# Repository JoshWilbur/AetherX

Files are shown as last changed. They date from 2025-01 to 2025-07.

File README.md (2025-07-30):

# AetherX

AetherX is a precision environmental sensor which can gather a number of statistics in real time. This device was designed with ease of use and portability in mind. This project is in a functional state and is considered "complete" for the time being. All features of this project, minus the microphone, are functional and calibrated. In the future, I plan to revisit this project to make improvements.

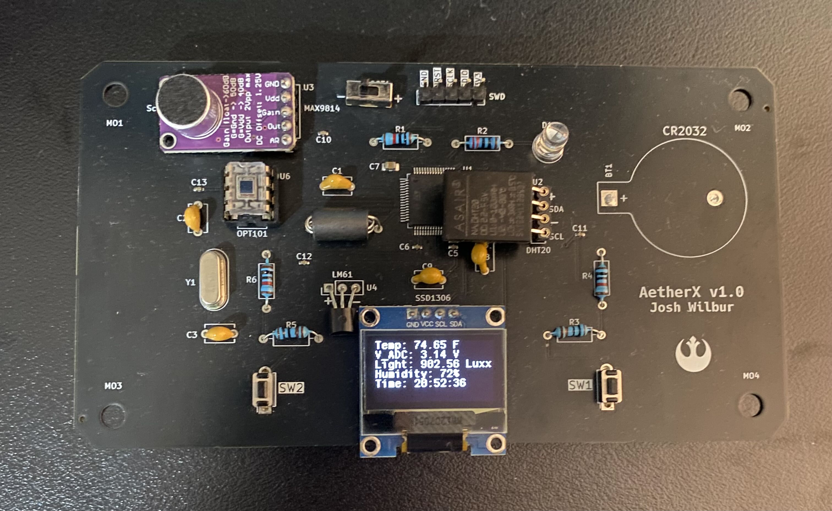
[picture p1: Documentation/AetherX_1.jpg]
AetherX 1.0


All code for this project is within Core/src. Schematic, PCB and assembly files are contained within AetherX_KiCad.

**Sensors:**

* LM61 - Temperature
* DHT20 - Relative humidity and temperature
* OPT101 - Light intensity at 650nm wavelength
* MAX9814 - Microphone with signal output

**Power**

This device is powered by 2x AA batteries. I tested the battery life of this device and found it can last ~1 month before a battery change is needed. Further improvements could be made to the code for additional power savings.

* 2/25/25: 5mA @ 3V (15mW)
* 7/30/25  3.8mA @ 3V (11.4mW)

# TODO:

**Software**

* Re-do reading functions with ADC rank (only do readings when displayed)
* Screens: ADC voltage stats, humidity, time/date, clicker, settings?
* Restructure data in structs?
* Signal processing for MAX9814 (frequency data via FFT, sound level in dB)

**Future Work**

* Wireless daughter boards (STM32WB55, 3D print sphere case?)
* Data logging (>24hrs)

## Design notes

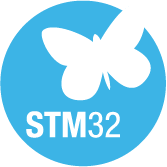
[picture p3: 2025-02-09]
AetherX_KiCad/pngs/st.png

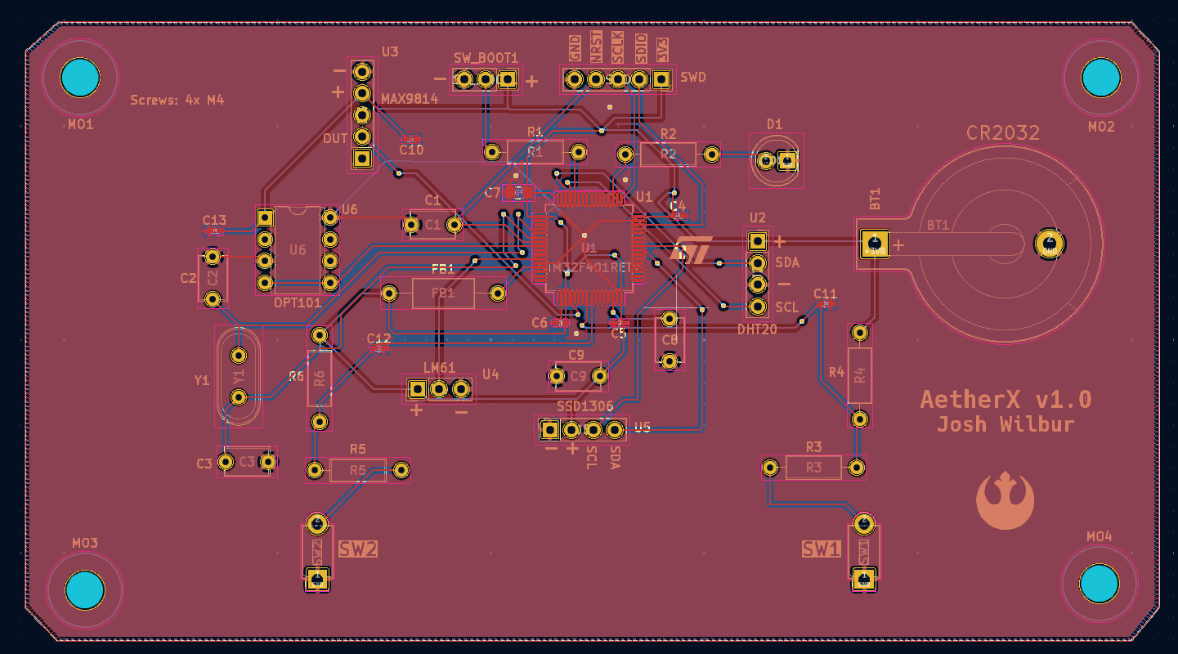
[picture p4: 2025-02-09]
Documentation/AetherX_PCB_V1.png

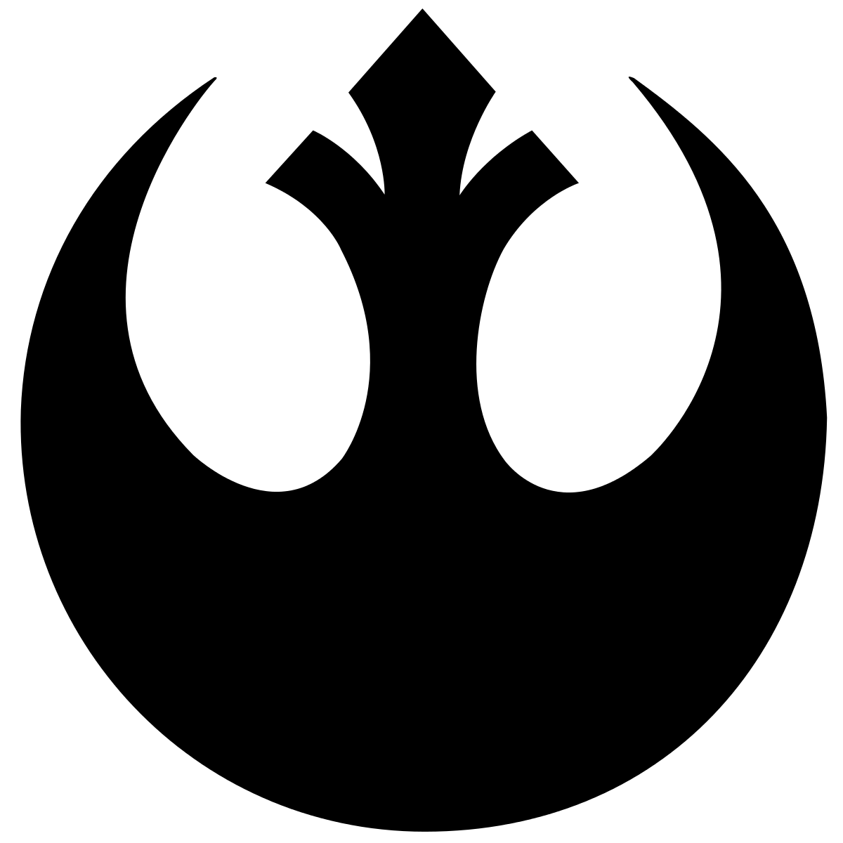
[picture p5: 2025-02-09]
AetherX_KiCad/pngs/star_wars_res.png

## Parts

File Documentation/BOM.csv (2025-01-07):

Line | Vendor | Vendor Part Number | Description | Unit Cost
1 | Digikey | LM61BIZ/NOPB-ND | Analog Temp Sensor | $1.07
2 | Digikey | 1528-5183-ND | Temp/Humidity Sensor | $5.50
3 | Digikey | 296-23090-5-ND | Optical Sensor 650nm | $7.38
4 | Adafruit | 1713 | Electret Microphone Amp | $7.95
5 | Digikey | 497-17429-ND | STM32F401 MCU 64LQFP | $6.60

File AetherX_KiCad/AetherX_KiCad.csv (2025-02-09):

Comment | Designator | Footprint | LCSC
0.1u | C4,C5,C6,C10,C11,C12,C13 | Capacitor_SMD:C_0402_1005Metric_Pad0.74x0.62mm_HandSolder | C141382
4.7u | C7 | Capacitor_SMD:C_0805_2012Metric_Pad1.18x1.45mm_HandSolder | C1779
STM32F401RETx | U1 | Package_QFP:LQFP-64_10x10mm_P0.5mm | C116978

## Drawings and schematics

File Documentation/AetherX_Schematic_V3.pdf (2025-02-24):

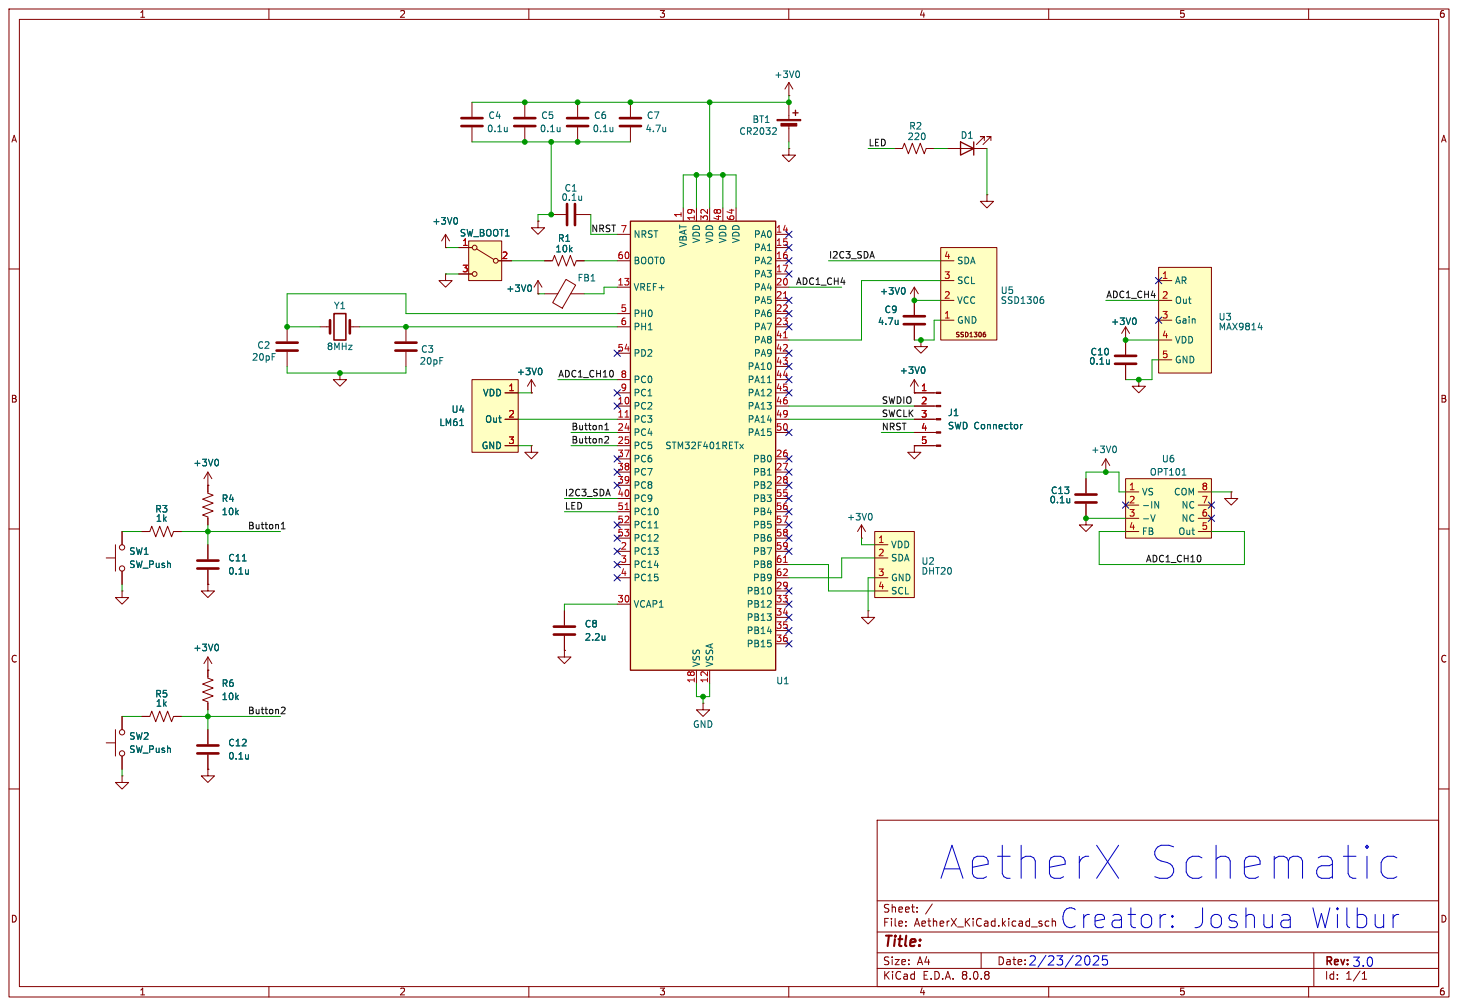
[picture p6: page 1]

1 PC2 10 PC3 11 VSSA 12 VREF+ 13 PA0 14 PA1 15 PA2 16 PA3 17 VSS 18 VDD 19 PC13 2 PA4 20 PA5 21 PA6 22 PA7 23 PC4 24 PC5 25 PB0 26 PB1 27 PB2 28 PB10 29 PC14 3 VCAP1 30 VDD 32 PB12 33 PB13 34 PB14 35 PB15 36 PC6 37 PC7 38 PC8 39 PC15 4 PC9 40 PA8 41 PA9 42 PA10 43 PA11 44 PA12 45 PA13 46 VDD 48 PA14 49 PH0 5 PA15 50 PC10 51 PC11 52 PC12 53 PD2 54 PB3 55 PB4 56 PB5 57 PB6 58 PB7 59 PH1 6 BOOT0 60 PB8 61 PB9 62 VDD 64 NRST 7 PC0 8 PC1 9 U1 STM32F401RETx C1

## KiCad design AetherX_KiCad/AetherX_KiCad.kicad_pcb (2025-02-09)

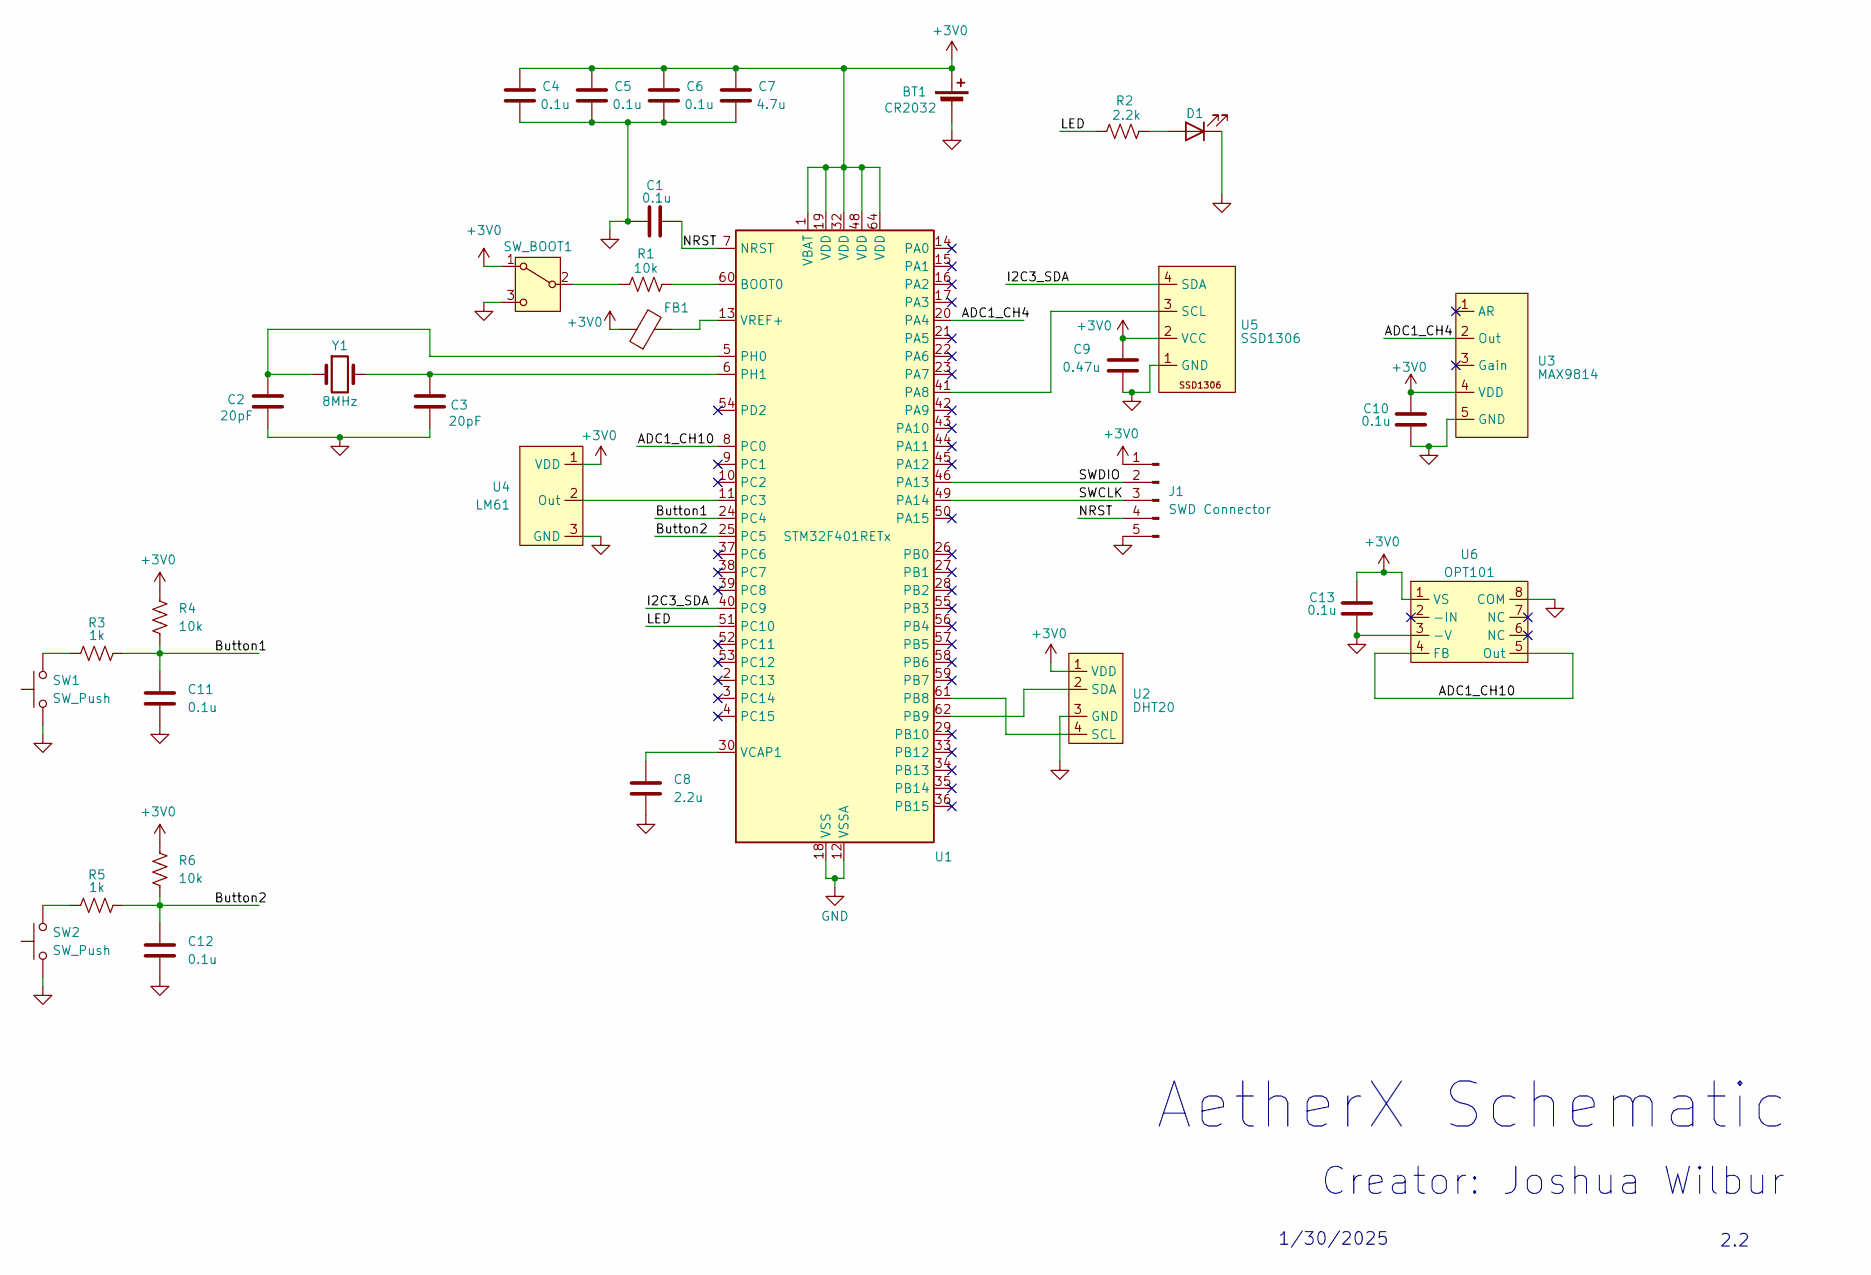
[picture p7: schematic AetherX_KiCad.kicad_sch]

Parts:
BT1: CR2032; BatteryHolder_Keystone_103_1x20mm
C1: 0.1u; C_Disc_D5.1mm_W3.2mm_P5.00mm
C2, C3: 20pF; C_Disc_D5.1mm_W3.2mm_P5.00mm
C4, C5, C6, C10, C11, C12, C13: 0.1u; C_0402_1005Metric_Pad0.74x0.62mm_HandSolder
C7: 4.7u; C_0805_2012Metric_Pad1.18x1.45mm_HandSolder
C8: 2.2u; C_Disc_D5.1mm_W3.2mm_P5.00mm
C9: 0.47u; C_Disc_D5.1mm_W3.2mm_P5.00mm
D1: LED; LED_D5.0mm
FB1: FerriteBead; L_Axial_L7.0mm_D3.3mm_P12.70mm_Horizontal_Fastron_MICC
J1: SWD Connector; PinSocket_1x05_P2.54mm_Vertical
R1, R4, R6: 10k; R_Axial_DIN0207_L6.3mm_D2.5mm_P10.16mm_Horizontal
R2: 2.2k; R_Axial_DIN0207_L6.3mm_D2.5mm_P10.16mm_Horizontal
R3, R5: 1k; R_Axial_DIN0207_L6.3mm_D2.5mm_P10.16mm_Horizontal
SW1, SW2: SW_Push; SW_PUSH_1P1T_6x3.5mm_H5.0_APEM_MJTP1250
SW_BOOT1: SW_SPDT; PinHeader_1x03_P2.54mm_Vertical
U1: STM32F401RETx; LQFP-64_10x10mm_P0.5mm
U2: DHT20; PinSocket_1x04_P2.54mm_Vertical
U3: MAX9814; PinSocket_1x05_P2.54mm_Vertical
U4: LM61; PinHeader_1x03_P2.54mm_Vertical
U5: SSD1306; PinSocket_1x04_P2.54mm_Vertical
U6: OPT101; DIP-8_W7.62mm
Y1: 8MHz; Crystal_HC49-4H_Vertical

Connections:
+3V0: BT1.1 (+), C4.1, C5.1, C6.1, C7.1, C9.1, C10.1, C13.1, FB1.1, J1.1, R4.1, R6.1, SW_BOOT1.1 (A), U1.1 (VBAT), U1.19 (VDD), U1.32 (VDD), U1.48 (VDD), U1.64 (VDD), U2.1 (VDD), U3.4 (VDD), U4.1 (VDD), U5.2 (VCC), U6.1 (VS); also elsewhere on the board
/ADC1_CH4: U1.20 (PA4), U3.2 (Out)
/ADC1_CH10: U1.8 (PC0), U6.4 (FB), U6.5 (Out)
/Button1: C11.1, R3.2, R4.2, U1.24 (PC4)
/Button2: C12.1, R5.2, R6.2, U1.25 (PC5)
/I2C3_SDA: U1.40 (PC9), U5.4 (SDA)
/LED: R2.1, U1.51 (PC10)
/NRST: C1.2, J1.4, U1.7 (NRST); also elsewhere on the board
/SWCLK: J1.3, U1.49 (PA14); also elsewhere on the board
/SWDIO: J1.2, U1.46 (PA13); also elsewhere on the board
GND: BT1.2 (-), C1.1, C2.2, C3.2, C4.2, C5.2, C6.2, C7.2, C8.2, C9.2, C10.2, C11.2, C12.2, C13.2, D1.1 (K), J1.5, SW1.1, SW2.1, SW_BOOT1.3 (C), U1.12 (VSSA), U1.18 (VSS), U1.31 (VSS), U1.47 (VSS), U1.63 (VSS), U2.3 (GND), U3.5 (GND), U4.3 (GND), U5.1 (GND), U6.3 (-V), U6.8 (COM); also elsewhere on the board
unnamed: D1.2 (A), R2.2
unnamed: R3.1, SW1.2
unnamed: R5.1, SW2.2
unnamed: R1.1, SW_BOOT1.2 (B)
unnamed: R1.2, U1.60 (BOOT0)
unnamed: U1.41 (PA8), U5.3 (SCL)
unnamed: U1.61 (PB8), U2.4 (SCL)
unnamed: U1.62 (PB9), U2.2 (SDA)
unnamed: U1.11 (PC3), U4.2 (Out)
unnamed: C2.1, U1.5 (PH0), Y1.1
unnamed: C3.1, U1.6 (PH1), Y1.2
unnamed: C8.1, U1.30 (VCAP1)
unnamed: FB1.2, U1.13 (VREF+)

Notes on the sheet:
AetherX Schematic
2.2
Creator: Joshua Wilbur
1/30/2025

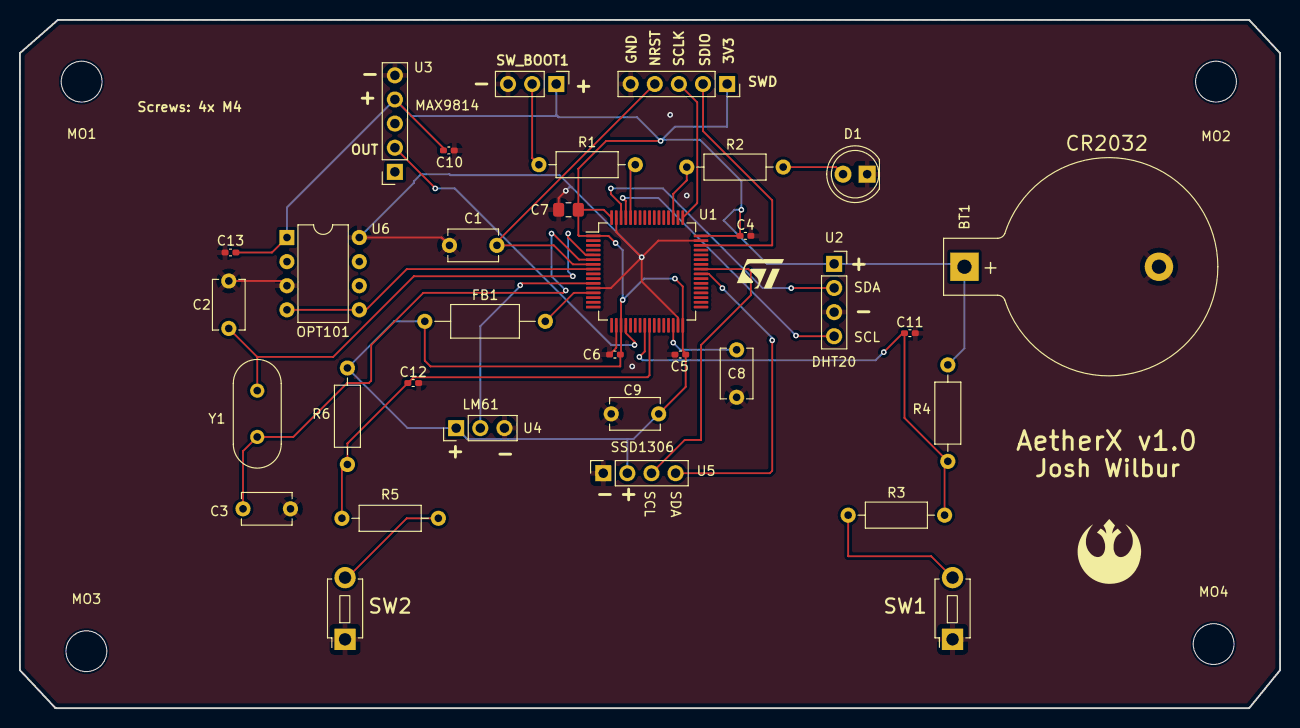
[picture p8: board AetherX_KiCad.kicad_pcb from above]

Board: 2 copper layers, 132.8 x 72.5 mm, 37 parts (0 on the bottom side), 24 nets.

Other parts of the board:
MO1, MO2, MO3, MO4: MountingHole_4.3mm_M4
SWD: SWD Connector; PinSocket_1x05_P2.54mm_Vertical

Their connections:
+3V0: SWD.1; also elsewhere on the board
/NRST: SWD.4; also elsewhere on the board
/SWCLK: SWD.3; also elsewhere on the board
/SWDIO: SWD.2; also elsewhere on the board
GND: SWD.5; also elsewhere on the board

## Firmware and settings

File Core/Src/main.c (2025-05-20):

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
/* Includes ------------------------------------------------------------------*/
#include "main.h"

/* USER CODE BEGIN Includes */
#include "LM61.h"
#include "OPT101.h"
#include "DHT20.h"
#include "MAX9814.h"
#include "ssd1306.h"
#include "screens.h"
#include "button.h"
/* USER CODE END Includes */

/* USER CODE BEGIN PD */
#define N_STAT 32
/* USER CODE END PD */

ADC_HandleTypeDef hadc1;
DMA_HandleTypeDef hdma_adc1;

I2C_HandleTypeDef hi2c1;
I2C_HandleTypeDef hi2c3;

RTC_HandleTypeDef hrtc;

TIM_HandleTypeDef htim2;

/* USER CODE BEGIN PV */
RTC_TimeTypeDef sTime;
/* USER CODE END PV */

void SystemClock_Config(void);
static void MX_GPIO_Init(void);
static void MX_DMA_Init(void);
static void MX_I2C1_Init(void);
static void MX_ADC1_Init(void);
static void MX_RTC_Init(void);
static void MX_I2C3_Init(void);
static void MX_TIM2_Init(void);
/* USER CODE BEGIN 0 */
// Measured ADC voltage
float ADC_VRef = 3.0;
int screen_state = 0;

// Buffer to hold DMA content from the MAX9814
uint16_t audio_buffer[1024];
/* USER CODE END 0 */

/**
  * @brief  The application entry point.
  * @retval int
  */
int main(void)
{

  /* MCU Configuration--------------------------------------------------------*/

  /* Reset of all peripherals, Initializes the Flash interface and the Systick. */
  HAL_Init();

  /* Configure the system clock */
  SystemClock_Config();

  /* Initialize all configured peripherals */
  MX_GPIO_Init();
  MX_DMA_Init();
  MX_I2C1_Init();
  MX_ADC1_Init();
  MX_RTC_Init();
  MX_I2C3_Init();
  MX_TIM2_Init();
  /* USER CODE BEGIN 2 */
  HAL_TIM_Base_Start_IT(&htim2);
  DHT20_Init();
  HAL_ADC_Start_DMA(&hadc1, (uint32_t *)audio_buffer, 1024);
  SSD1306_Init();
  /* USER CODE END 2 */
  // DECLARATION OF VARIABLES
  float temp_val, temp_avg, light_val, light_avg, hum_avg = -1;
  int hum_val = -1;
  int MAX9814 = -1;

  // Buffers for averages
  float temp_buf[N_STAT] = {0};
  float light_buf[N_STAT] = {0};
  float hum_buf[N_STAT] = {0};
  uint8_t index = 0;

  // Highs and lows
  float temp_low = 200.0f;
  float temp_high = -100.0f;
  float light_low = 9000.0f;
  float light_high = -9000.0f;
  float hum_low = 101.0f;
  float hum_high = -1.0f;
  /* USER CODE BEGIN WHILE */

  SSD1306_ScrollLeft(0,7);
  while(1){
	  // Handle STOP mode activation
	  if (stop_flag == 1){
		  SSD1306_TurnOff(); // Shut off display
		  for (int i = 0; i < 6; i++){
			  HAL_GPIO_TogglePin(GPIOC, GPIO_PIN_10);
			  HAL_Delay(100);
		  }
		  HAL_GPIO_WritePin(GPIOC, GPIO_PIN_10, GPIO_PIN_RESET); // Ensure LED is off

		  // Disable peripherals
		  HAL_I2C_DeInit(&hi2c1);
		  HAL_I2C_DeInit(&hi2c3);
		  HAL_ADC_DeInit(&hadc1);
		  HAL_SuspendTick();
		  HAL_PWR_EnterSTOPMode(PWR_LOWPOWERREGULATOR_ON, PWR_SLEEPENTRY_WFI); // Enter stop mode

		  // After STOP mode ends...
		  HAL_ResumeTick();
		  SystemClock_Config();

		  // Re-enable peripherals
		  MX_I2C1_Init();
		  MX_I2C3_Init();
		  MX_ADC1_Init();
		  SSD1306_Init();
		  stop_flag = 0;
	  }

	  // Update time
	  RTC_UpdateTime();

	  // Track button inputs
	  if (button_flag != 0) Button_History();

	  // Obtain readings from sensors with timer interrupt
	  if (read_flag == 1){
		  // Sensor readings
		  temp_val = LM61_Temp(1);
		  light_val = OPT101_Lux();
		  MAX9814 = MAX9814_Read();
		  hum_val = DHT20_Humidity();
		  ADC_VRef = Read_VADC();

		  // Detect high and low temperatures
		  Detect_Extremum(temp_val, &temp_low, &temp_high);
		  Detect_Extremum(light_val, &light_low, &light_high);
		  Detect_Extremum(hum_val, &hum_low, &hum_high);

		  // Place data into buffers for easier avg processing
		  temp_buf[index] = temp_val;
		  light_buf[index] = light_val;
		  hum_buf[index] = hum_val;
		  index++;

		  // Reset index to stay in bounds
		  if (index == N_STAT-1){
			  temp_avg = Average_Gen(temp_buf, N_STAT);
			  light_avg = Average_Gen(light_buf, N_STAT);
			  hum_avg = Average_Gen(hum_buf, N_STAT);
			  index = 0;
		  }
		  read_flag = 0; // Reset flag
	  }

	  // Select screen with switch 1
	  if (screen_flag == 1){
		  screen_state++;
		  SSD1306_Stopscroll();
		  SSD1306_Clear();
		  screen_flag = 0;
	  }

	  // Toggle LED with switch 2
	  if (LED_flag == 1){
		  HAL_GPIO_TogglePin(GPIOC, GPIO_PIN_10);
		  LED_flag = 0;
	  }

	  // Display readings on OLED using switch case
	  switch (screen_state) {
		  case 0:
			  SSD1306_Show_Readings(temp_val, ADC_VRef, light_val, hum_val);
			  break;

		  case 1:
			  SSD1306_Screen(temp_val, temp_avg, "Temperature", "F", temp_high, temp_low);
			  break;

		  case 2:
			  SSD1306_Screen(light_val, light_avg, "Light", "LUX", light_high, light_low);
			  break;

		  case 3:
			  SSD1306_Screen(hum_val, hum_avg, "Humidity", "%", hum_high, hum_low);
			  break;

		  default:
			  SSD1306_Show_Readings(temp_val, ADC_VRef, light_val, hum_val);
			  screen_state = 0;
			  break;
	  }

	  SSD1306_UpdateScreen();
	  //HAL_Delay(delay_ms);
  }
    /* USER CODE END WHILE */

}

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
/* USER CODE BEGIN 4 */
float Read_VADC(void){
	// Set channel to internal reference channel
	ADC_ChannelConfTypeDef sConfig = {0};
	sConfig.Channel = ADC_CHANNEL_VREFINT;
	sConfig.Rank = 1;
	sConfig.SamplingTime = ADC_SAMPLETIME_3CYCLES;
	if (HAL_ADC_ConfigChannel(&hadc1, &sConfig) != HAL_OK) Error_Handler();

    uint32_t adc_value = 0;
    HAL_ADC_Start(&hadc1);
    HAL_ADC_PollForConversion(&hadc1, HAL_MAX_DELAY);
    adc_value = HAL_ADC_GetValue(&hadc1);
    HAL_ADC_Stop(&hadc1);
    float VREF = 1.2f; // Define reference voltage
    float voltage = (VREF * 4095.0f) / adc_value;

    if (voltage == 0) return 3.0;
    return voltage;
}

// Updates RTC time
void RTC_UpdateTime(void) {
    HAL_RTC_GetTime(&hrtc, &sTime, RTC_FORMAT_BIN);
    HAL_RTC_GetDate(&hrtc, &(RTC_DateTypeDef){0}, RTC_FORMAT_BIN); // Read date to unlock RTC registers
}

// Average generation function
float Average_Gen(float *readings, int len){
	float sum = 0;
	for (int i = 0; i < len; i++) sum += readings[i];
	float avg = sum / ((float)(len - 1));
	return avg;
}

// Function to update the high or low metric
void Detect_Extremum(float reading, float *low, float *high){
	if (reading > *high) *high = reading;
	if (reading < *low) *low = reading;
}

/* USER CODE END 4 */
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


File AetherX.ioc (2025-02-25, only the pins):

Mcu.UserName=STM32F401RETx
PA13.Signal=SYS_JTMS-SWDIO
PA14.Signal=SYS_JTCK-SWCLK
PA4.Signal=ADCx_IN4
PA8.Signal=I2C3_SCL
PB3.Signal=SYS_JTDO-SWO
PB8.Signal=I2C1_SCL
PB9.Signal=I2C1_SDA
PC0.Signal=ADCx_IN10
PC10.Signal=GPIO_Output
PC3.Signal=ADCx_IN13
PC4.Signal=GPIO_Input
PC5.Signal=GPIO_Input
PC9.Signal=I2C3_SDA

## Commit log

2024-12-24 add STM32 project files
2024-12-25 i2c working with the altmeter
2024-12-30 LM61 temp sensor code written, device works great
2024-12-31 OPT101 sensor code written, calibration needed
2025-01-01 DHT20 sensor code written
2025-01-03 DMA is working for the mic! signal processing can now begin
2025-01-03 begin KiCad schematic for Aether
    [AetherX_KiCad.kicad_pcb, AetherX_KiCad.kicad_sch]
2025-01-07 ssd1306 display is talking, static output though
    [BOM.csv]
2025-01-19 update schematic
    [AetherX_KiCad.kicad_sch]
2025-01-25 internal ADC VRef code added
    [AetherX_KiCad.kicad_sch]
2025-01-30 schematic V2 complete
    [AetherX_KiCad.kicad_sch]
2025-02-07 first PCB complete
    [AetherX_KiCad.kicad_pcb, AetherX_KiCad.kicad_sch]
2025-02-09 PCB ordered, uploaded BOM and gerber files
    [AetherX_KiCad-B_Cu.gbl, AetherX_KiCad-B_Mask.gbs, AetherX_KiCad-B_Paste.gbp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]
2025-02-24 schematic v3 uploaded
    [AetherX_KiCad.kicad_sch]
2025-02-24 various code improvements: opt101, LED, input interrupts, screens...
2025-02-24 update readings to use a timer interrupt
2025-02-25 fixed ADC internal voltage, now displayed on readings screen
    [main.c]
2025-04-18 battery test complete, 26 days on 2x AA batteries
2025-05-20 finally fixed display, added high/low stats
    [main.c]
2025-05-20 cleanup after fixing display
    [main.c]
